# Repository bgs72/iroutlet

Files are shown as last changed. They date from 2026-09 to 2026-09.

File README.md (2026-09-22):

# IrOutlet
IrOutlet is an 8-port power outlet. Each power outlet can be switched on or off using an IR remote.

## Design details
A [TSOP4836](KiCad/doc/tsop4836.pdf) IR receiver converts the IR light into a bit stream. This bit stream is decoded by a [PIC16F15325](KiCad/doc/pic16f15325.pdf) microcontroller.
When the IR signal is decoded, the microcontroller performs an action if the signal matches a supported IR address/command listed below:

| Address | Command | Action |
|---|---| ---|
| `0b00101` | `0b00000000` | Switch all outlets on  |
| `0b00101` | `0b00000001` | Switch outlet 1 on |
| `0b00101` | `0b00000010` | Switch outlet 2 on |
| `0b00101` | `0b00000011` | Switch outlet 3 on |
| `0b00101` | `0b00000100` | Switch outlet 4 on |
| `0b00101` | `0b00000101` | Switch outlet 5 on |
| `0b00101` | `0b00000110` | Switch outlet 6 on |
| `0b00101` | `0b00000111` | Switch outlet 7 on |
| `0b00101` | `0b00001000` | Switch outlet 8 on |
| `0b00101` | `0b00001001` | Switch all outlets off |
| `0b00101` | `0b00100000` | Switch outlet 1 off |
| `0b00101` | `0b00100001` | Switch outlet 2 off |
| `0b00101` | `0b00110010` | Switch outlet 3 off |
| `0b00101` | `0b00110101` | Switch outlet 4 off |
| `0b00101` | `0b00110100` | Switch outlet 5 off |
| `0b00101` | `0b00110110` | Switch outlet 6 off |
| `0b00101` | `0b00101001` | Switch outlet 7 off |
| `0b00101` | `0b00111110` | Switch outlet 8 off |

## Notes

1. Address `0b00101` corresponds to the address of a Marantz remote control I had available.

2. Below are some oscilloscope captures measured at the output pin of the [TSOP4836](KiCad/doc/tsop4836.pdf) while using the Marantz remote control:<br>
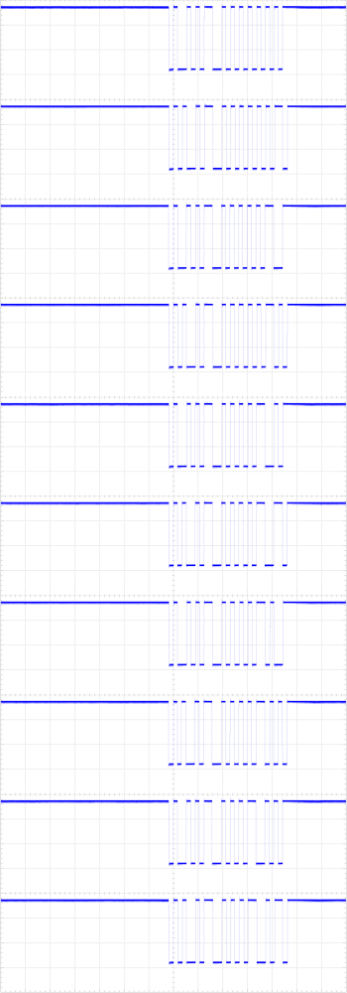
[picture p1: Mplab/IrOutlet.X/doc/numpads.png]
IR captures
  

## Development tree

The project consists of three major folders:

1. [Mplab](https://www.microchip.com/en-us/tools-resources/develop/mplab-x-ide)
  
  This folder contains the bare-metal code for the Microchip [PIC16F15325](KiCad/doc/pic16f15325.pdf) controller.
  [MPLAB X IDE](https://www.microchip.com/en-us/tools-resources/develop/mplab-x-ide) or [VSCode](https://code.visualstudio.com/) with the MPLAB extension can be used as the development environment (using the free [XC8](https://www.microchip.com/en-us/tools-resources/develop/mplab-xc-compilers/xc8) compiler).
  
  Major implementation files:
  - [rc5.h](Mplab/IrOutlet.X/rc5.h): RC5 decoder API
  - [rc5.c](Mplab/IrOutlet.X/rc5.c): RC5 decoder implementation
  - [interrupts.c](Mplab/IrOutlet.X/interrupts.c): [TSOP4836](KiCad/doc/tsop4836.pdf) and timer interrupt handlers
  - [main.c](Mplab/IrOutlet.X/main.c): Controller setup and IR handling

2. [KiCad](https://www.kicad.org)
    
    This folder contains the IrOutlet schematic and PCB design.

    - The schematic consists of two major parts:
      1. The controller:<br>
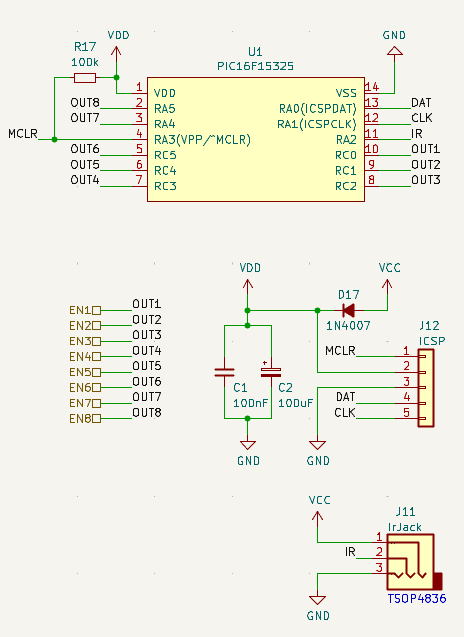
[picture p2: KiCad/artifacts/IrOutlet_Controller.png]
IrOutlet Controller
        
      2. The relay driver:<br>
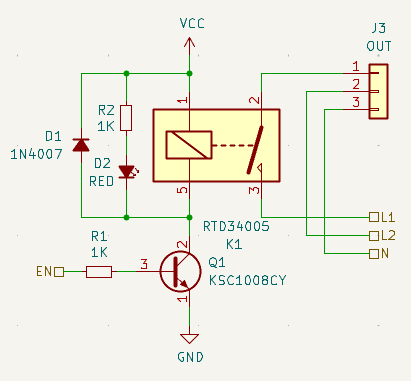
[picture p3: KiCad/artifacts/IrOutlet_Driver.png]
IrOutlet Driver
        
    - The components are laid out on a single-sided PCB:
      1. Component layout:<br>
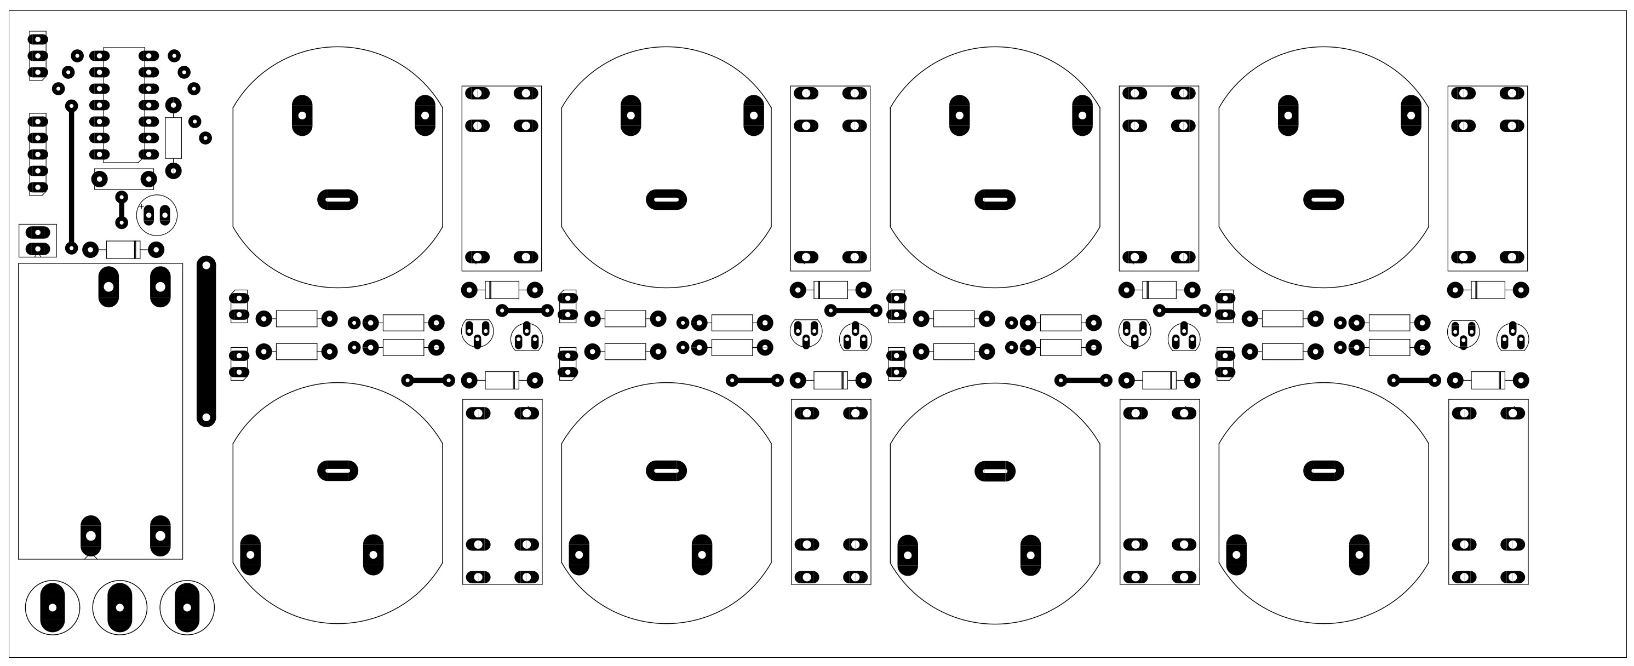
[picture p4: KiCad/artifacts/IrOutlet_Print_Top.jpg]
IrOutlet Component Layout
        
      2. Bottom mask:<br>
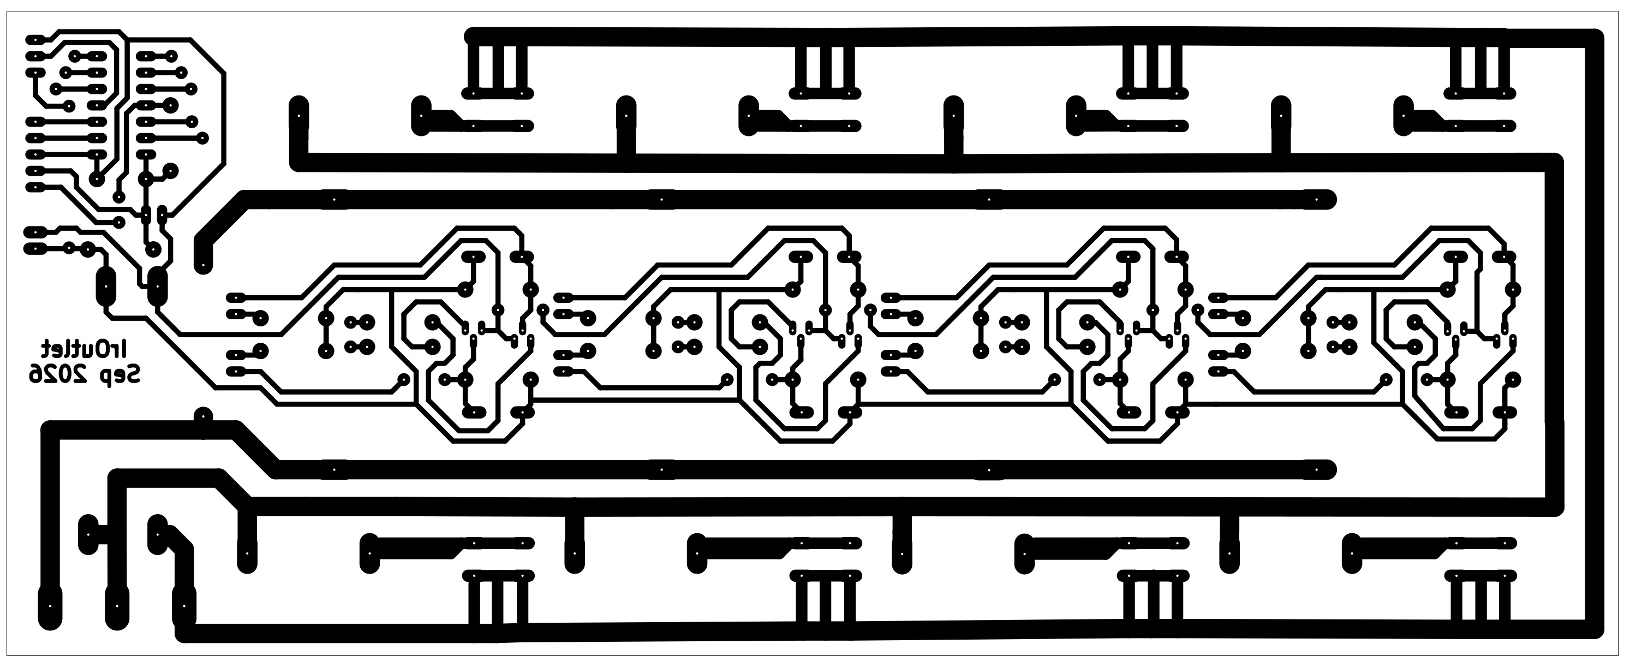
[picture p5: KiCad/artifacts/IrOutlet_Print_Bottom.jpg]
IrOutlet Bottom Mask
        
 
3. [FreeCAD](https://www.freecad.org)

    This folder contains the 3D enclosure model for the IrOutlet.
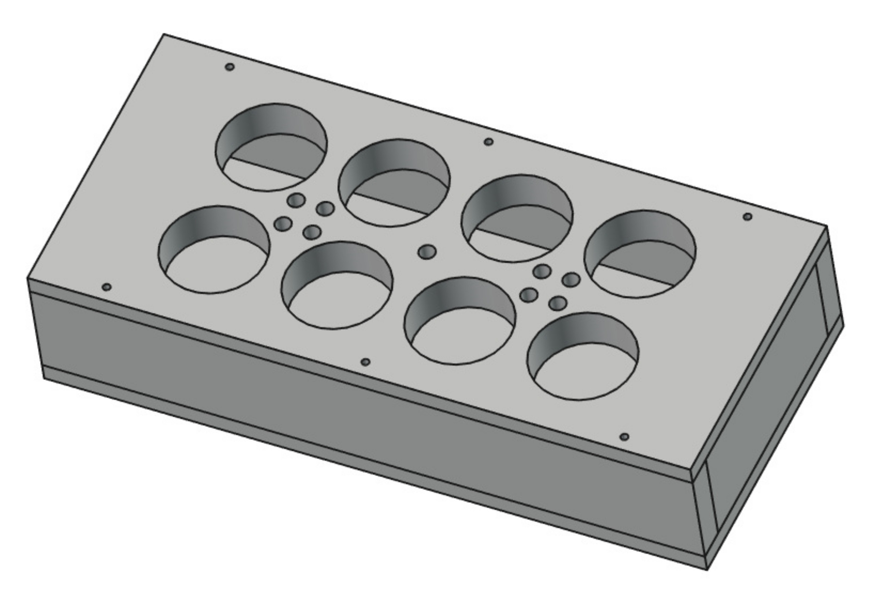
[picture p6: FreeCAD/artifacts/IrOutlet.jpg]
IrOutlet 3D model


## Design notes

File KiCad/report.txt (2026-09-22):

Info: Processing symbol 'K8:IrOutlet:RELAY_TE_RTD3405'.
Info: Processing symbol 'R15:IrOutlet:RES_H'.
Info: Processing symbol 'R6:IrOutlet:RES_H'.
Info: Processing symbol 'K6:IrOutlet:RELAY_TE_RTD3405'.
Info: Processing symbol 'J6:IrOutlet:OUTLET'.
Info: Processing symbol 'R16:IrOutlet:RES_H'.
Info: Processing symbol 'J5:IrOutlet:OUTLET'.
Info: Processing symbol 'R5:IrOutlet:RES_H'.
Info: Processing symbol 'R17:IrOutlet:RES_H'.
Info: Processing symbol 'J4:IrOutlet:OUTLET'.
Info: Processing symbol 'J7:IrOutlet:OUTLET'.
Info: Processing symbol 'R4:IrOutlet:RES_H'.
Info: Processing symbol 'U1:IrOutlet:DIP-14'.
Info: Processing symbol 'J3:IrOutlet:OUTLET'.
Info: Processing symbol 'J2:IrOutlet:TB_1x2'.
Info: Processing symbol 'PS1:IrOutlet:IRM-05-5'.
Info: Processing symbol 'C1:IrOutlet:C_L7.62mm_W3.2mm'.
Info: Processing symbol 'R3:IrOutlet:RES_H'.
Info: Processing symbol 'J1:IrOutlet:TB_1x3'.
Info: Processing symbol 'D17:IrOutlet:DIODE_H'.
Info: Processing symbol 'J10:IrOutlet:OUTLET'.
Info: Processing symbol 'R10:IrOutlet:RES_H'.
Info: Processing symbol 'K1:IrOutlet:RELAY_TE_RTD3405'.
Info: Processing symbol 'K2:IrOutlet:RELAY_TE_RTD3405'.
Info: Processing symbol 'J12:IrOutlet:HDR_1x5'.
Info: Processing symbol 'R11:IrOutlet:RES_H'.
Info: Processing symbol 'J11:IrOutlet:HDR_1x3'.
Info: Processing symbol 'R9:IrOutlet:RES_H'.
Info: Processing symbol 'K3:IrOutlet:RELAY_TE_RTD3405'.
Info: Processing symbol 'R12:IrOutlet:RES_H'.
Info: Processing symbol 'K7:IrOutlet:RELAY_TE_RTD3405'.
Info: Processing symbol 'R8:IrOutlet:RES_H'.
Info: Processing symbol 'R13:IrOutlet:RES_H'.
Info: Processing symbol 'J9:IrOutlet:OUTLET'.
Info: Processing symbol 'K4:IrOutlet:RELAY_TE_RTD3405'.
Info: Processing symbol 'J8:IrOutlet:OUTLET'.
Info: Processing symbol 'R7:IrOutlet:RES_H'.
Info: Processing symbol 'R14:IrOutlet:RES_H'.
Info: Processing symbol 'K5:IrOutlet:RELAY_TE_RTD3405'.
Info: Processing symbol 'Q8:IrOutlet:TO-92'.
Info: Processing symbol 'D12:IrOutlet:HDR_1x2'.
Info: Processing symbol 'C2:IrOutlet:CAP_6.3mm_P2.50mm'.
Info: Processing symbol 'R1:IrOutlet:RES_H'.
Info: Processing symbol 'D11:IrOutlet:DIODE_H'.
Info: Processing symbol 'Q4:IrOutlet:TO-92'.
Info: Processing symbol 'D10:IrOutlet:HDR_1x2'.
Info: Processing symbol 'R2:IrOutlet:RES_H'.
Info: Processing symbol 'D2:IrOutlet:HDR_1x2'.
Info: Processing symbol 'D9:IrOutlet:DIODE_H'.
Info: Processing symbol 'D1:IrOutlet:DIODE_H'.
Info: Processing symbol 'Q5:IrOutlet:TO-92'.
Info: Processing symbol 'D3:IrOutlet:DIODE_H'.
Info: Processing symbol 'D8:IrOutlet:HDR_1x2'.
Info: Processing symbol 'D4:IrOutlet:HDR_1x2'.
Info: Processing symbol 'D7:IrOutlet:DIODE_H'.
Info: Processing symbol 'Q6:IrOutlet:TO-92'.
Info: Processing symbol 'D6:IrOutlet:HDR_1x2'.
Info: Processing symbol 'Q7:IrOutlet:TO-92'.
Info: Processing symbol 'D5:IrOutlet:DIODE_H'.
Info: Processing symbol 'D16:IrOutlet:HDR_1x2'.
Info: Processing symbol 'Q1:IrOutlet:TO-92'.
Info: Processing symbol 'D13:IrOutlet:DIODE_H'.
Info: Processing symbol 'Q3:IrOutlet:TO-92'.
Info: Processing symbol 'D14:IrOutlet:HDR_1x2'.
Info: Processing symbol 'D15:IrOutlet:DIODE_H'.
Info: Processing symbol 'Q2:IrOutlet:TO-92'.
Reconnect R8 pin 2 from /RelaisDriver1.4/EN to /IrController/OUT4.
Reconnect R10 pin 1 from Net-(Q5-Pad3) to Net-(Q5-B).
Add net /IrController/OUT4.
Add net /IrController/OUT5.
Reconnect R2 pin 1 from Net-(Q1-Pad3) to Net-(Q1-B).
Change R3 reference designator to R2.
Reconnect R10 pin 2 from /RelaisDriver2.1/EN to /IrController/OUT5.
Reconnect R8 pin 1 from Net-(Q4-Pad3) to Net-(Q4-B).
Add net Net-(Q4-B).
Update R8 footprint filters to 'R_*'.
Update R8 sheetfile to 'RelaisDriver1.kicad_sch'.
Update R8 sheetname to '/RelaisDriver1.4/'.
Update R8 fields.
Change R8 reference designator to R7.
Update R10 unit metadata.
Update R9 footprint filters to 'R_*'.
Update R10 fields.
Change R10 reference designator to R9.
Update R10 sheetname to '/RelaisDriver2.1/'.
Update R9 unit metadata.
Update R10 sheetfile to 'RelaisDriver2.kicad_sch'.
Update R2 unit metadata.
Reconnect R9 pin 1 from Net-(D9-Pad2) to Net-(D8-A).
Add net Net-(D8-A).
Add net Net-(Q1-B).
Update R8 unit metadata.
Reconnect R2 pin 2 from /RelaisDriver1.1/EN to /IrController/OUT1.
Update R10 footprint filters to 'R_*'.
Update R9 sheetfile to 'RelaisDriver1.kicad_sch'.
Add net /IrController/OUT1.
Update R9 sheetname to '/RelaisDriver1.4/'.
Add net Net-(Q5-B).
Update R9 fields.
Change R9 reference designator to R8.
Add net /IrController/OUT2.
Reconnect R5 pin 1 from Net-(D5-Pad2) to Net-(D4-A).
Add net Net-(D4-A).
Update R5 footprint filters to 'R_*'.
Update R5 sheetfile to 'RelaisDriver1.kicad_sch'.
Update R5 sheetname to '/RelaisDriver1.2/'.
Update R5 fields.
Change R5 reference designator to R4.
Update R3 footprint filters to 'R_*'.
Update R4 unit metadata.
Reconnect R4 pin 2 from /RelaisDriver1.2/EN to /IrController/OUT2.
Update R5 unit metadata.
Reconnect R4 pin 1 from Net-(Q2-Pad3) to Net-(Q2-B).
Add net Net-(Q2-B).
Update R4 footprint filters to 'R_*'.
Update R4 sheetfile to 'RelaisDriver1.kicad_sch'.
Add net Net-(D2-A).
Update R4 sheetname to '/RelaisDriver1.2/'.
Update R4 fields.
Change R4 reference designator to R3.
Reconnect R3 pin 1 from Net-(D3-Pad2) to Net-(D2-A).
Update R3 unit metadata.
Reconnect R6 pin 1 from Net-(Q3-Pad3) to Net-(Q3-B).
Update R3 fields.
Reconnect R7 pin 1 from Net-(D7-Pad2) to Net-(D6-A).
Add net Net-(D6-A).
Update R7 footprint filters to 'R_*'.
Update R7 sheetfile to 'RelaisDriver1.kicad_sch'.
Update R7 sheetname to '/RelaisDriver1.3/'.
Update R7 fields.
Change R7 reference designator to R6.
Update R3 sheetname to '/RelaisDriver1.1/'.
Update R6 unit metadata.
Update R7 unit metadata.
Add net Net-(Q3-B).
Reconnect R6 pin 2 from /RelaisDriver1.3/EN to /IrController/OUT3.
Add net /IrController/OUT3.
Update R6 footprint filters to 'R_*'.
Update R6 sheetfile to 'RelaisDriver1.kicad_sch'.
Update R6 sheetname to '/RelaisDriver1.3/'.
Update R6 fields.
Update R3 sheetfile to 'RelaisDriver1.kicad_sch'.
Change R6 reference designator to R5.
Add net /IrController/OUT6.
Update R1 sheetfile to 'IrController.kicad_sch'.
Reconnect U1 pin 9 from /RelaisDriver1.2/EN to /IrController/OUT2.
Reconnect U1 pin 8 from /RelaisDriver1.3/EN to /IrController/OUT3.
Reconnect U1 pin 10 from /RelaisDriver1.1/EN to /IrController/OUT1.
Reconnect U1 pin 6 from /RelaisDriver2.1/EN to /IrController/OUT5.
Reconnect U1 pin 5 from /RelaisDriver2.2/EN to /IrController/OUT6.
Reconnect U1 pin 7 from /RelaisDriver1.4/EN to /IrController/OUT4.
Reconnect U1 pin 3 from /RelaisDriver2.4/EN to /IrController/OUT7.
Update U1 sheetfile to 'IrController.kicad_sch'.
Update U1 sheetname to '/IrController/'.
Update U1 fields.
Update R1 unit metadata.
Update R1 footprint filters to 'R_*'.
Reconnect U1 pin 2 from /RelaisDriver2.3/EN to /IrController/OUT8.
Update R1 sheetname to '/IrController/'.
Update R1 fields.
Change R1 reference designator to R17.
Update R17 unit metadata.
Reconnect R17 pin 1 from Net-(D17-Pad2) to Net-(D16-A).
Add net Net-(D16-A).
Update R17 footprint filters to 'R_*'.
Update R17 sheetfile to 'RelaisDriver2.kicad_sch'.
Update R17 sheetname to '/RelaisDriver2.3/'.
Update R17 fields.
Change R17 reference designator to R16.
Update R16 unit metadata.
Reconnect via from /RelaisDriver1.3/EN to /IrController/OUT3.
Reconnect via from /RelaisDriver1.1/EN to /IrController/OUT1.
Reconnect via from /RelaisDriver1.1/EN to /IrController/OUT1.
Reconnect via from /RelaisDriver2.3/EN to /IrController/OUT8.
Reconnect via from /RelaisDriver2.3/EN to /IrController/OUT8.
Reconnect via from /RelaisDriver2.4/EN to /IrController/OUT7.
Reconnect via from /RelaisDriver2.4/EN to /IrController/OUT7.
Reconnect via from /RelaisDriver2.2/EN to /IrController/OUT6.
Reconnect via from /RelaisDriver2.2/EN to /IrController/OUT6.
Reconnect via from /RelaisDriver2.1/EN to /IrController/OUT5.
Reconnect via from /RelaisDriver2.1/EN to /IrController/OUT5.
Reconnect via from /RelaisDriver1.4/EN to /IrController/OUT4.
Reconnect via from /RelaisDriver1.4/EN to /IrController/OUT4.
Reconnect R16 pin 1 from Net-(Q8-Pad3) to Net-(Q8-B).
Reconnect via from /RelaisDriver1.3/EN to /IrController/OUT3.
Reconnect via from /RelaisDriver1.2/EN to /IrController/OUT2.
Reconnect via from /RelaisDriver1.2/EN to /IrController/OUT2.
Reconnect via from Net-(D16-Pad2) to Net-(D15-A).
Reconnect via from Net-(D16-Pad2) to Net-(D15-A).
Reconnect via from Net-(D14-Pad2) to Net-(D13-A).
Reconnect via from Net-(D14-Pad2) to Net-(D13-A).
Reconnect via from Net-(D12-Pad2) to Net-(D11-A).
Reconnect via from Net-(D12-Pad2) to Net-(D11-A).
Reconnect via from Net-(D10-Pad2) to Net-(D10-K).
Reconnect via from Net-(D10-Pad2) to Net-(D10-K).
Update U1 unit metadata.
Add net Net-(Q6-B).
Update R13 unit metadata.
Reconnect R13 pin 1 from Net-(D13-Pad2) to Net-(D12-A).
Add net Net-(D12-A).
Update R13 footprint filters to 'R_*'.
Update R13 sheetfile to 'RelaisDriver2.kicad_sch'.
Update R13 sheetname to '/RelaisDriver2.2/'.
Update R13 fields.
Change R13 reference designator to R12.
Update R12 unit metadata.
Reconnect R12 pin 2 from /RelaisDriver2.2/EN to /IrController/OUT6.
Update PS1 sheetfile to 'PowerSupply.kicad_sch'.
Reconnect R12 pin 1 from Net-(Q6-Pad3) to Net-(Q6-B).
Change R14 reference designator to R13.
Update R12 footprint filters to 'R_*'.
Update R12 sheetfile to 'RelaisDriver2.kicad_sch'.
Update R12 sheetname to '/RelaisDriver2.2/'.
Update R12 fields.
Change R12 reference designator to R11.
Update R11 unit metadata.
Reconnect R11 pin 1 from Net-(D11-Pad2) to Net-(D10-A).
Add net Net-(D10-A).
Update R11 footprint filters to 'R_*'.
Update R11 sheetfile to 'RelaisDriver2.kicad_sch'.
Update R11 sheetname to '/RelaisDriver2.1/'.
Update R11 fields.
Update R15 sheetfile to 'RelaisDriver2.kicad_sch'.
Add net Net-(Q8-B).
Reconnect R16 pin 2 from /RelaisDriver2.3/EN to /IrController/OUT8.
Add net /IrController/OUT8.
Update R16 footprint filters to 'R_*'.
Update R16 sheetfile to 'RelaisDriver2.kicad_sch'.
Update R16 sheetname to '/RelaisDriver2.3/'.
Update R16 fields.
Change R16 reference designator to R15.
Update R15 unit metadata.
Reconnect R15 pin 1 from Net-(D15-Pad2) to Net-(D14-A).
Add net Net-(D14-A).
Update R15 footprint filters to 'R_*'.
Change R11 reference designator to R10.
Update R15 sheetname to '/RelaisDriver2.4/'.
Update R15 fields.
Change R15 reference designator to R14.
Update R14 unit metadata.
Reconnect R14 pin 2 from /RelaisDriver2.4/EN to /IrController/OUT7.
Add net /IrController/OUT7.
Reconnect R14 pin 1 from Net-(Q7-Pad3) to Net-(Q7-B).
Add net Net-(Q7-B).
Update R14 footprint filters to 'R_*'.
Update R14 sheetfile to 'RelaisDriver2.kicad_sch'.
Update R14 sheetname to '/RelaisDriver2.4/'.
Update R14 fields.
Update J4 fields.
Add net Net-(J7-Pin_2).
Update J5 footprint filters to 'Connector*:*_1x??_*'.
Update J5 sheetfile to 'RelaisDriver2.kicad_sch'.
Update J5 sheetname to '/RelaisDriver2.1/'.
Update J5 fields.
Change J5 reference designator to J7.
Update J4 unit metadata.
Reconnect J4 pin 1 from Net-(J4-Pad1) to Net-(J6-Pin_1).
Add net Net-(J6-Pin_1).
Update J4 footprint filters to 'Connector*:*_1x??_*'.
Update J4 sheetfile to 'RelaisDriver1.kicad_sch'.
Update J4 sheetname to '/RelaisDriver1.4/'.
Reconnect J5 pin 2 from Net-(J5-Pad2) to Net-(J7-Pin_2).
Change J4 reference designator to J6.
Update J3 unit metadata.
Reconnect J3 pin 1 from Net-(J3-Pad1) to Net-(J5-Pin_1).
Add net Net-(J5-Pin_1).
Update J3 footprint filters to 'Connector*:*_1x??_*'.
Update J3 sheetfile to 'RelaisDriver1.kicad_sch'.
Update J3 sheetname to '/RelaisDriver1.3/'.
Update J3 fields.
Change J3 reference designator to J5.
Update J2 unit metadata.
Reconnect J2 pin 1 from Net-(J2-Pad1) to Net-(J4-Pin_1).
Update J7 sheetname to '/RelaisDriver2.4/'.
Reconnect J8 pin 2 from Net-(J8-Pad2) to Net-(J10-Pin_2).
Add net Net-(J10-Pin_2).
Update J8 footprint filters to 'Connector*:*_1x??_*'.
Update J8 sheetfile to 'RelaisDriver2.kicad_sch'.
Update J8 sheetname to '/RelaisDriver2.3/'.
Update J8 fields.
Change J8 reference designator to J10.
Update J7 unit metadata.
Reconnect J7 pin 2 from Net-(J7-Pad2) to Net-(J9-Pin_2).
Add net Net-(J9-Pin_2).
Update J7 footprint filters to 'Connector*:*_1x??_*'.
Update J7 sheetfile to 'RelaisDriver2.kicad_sch'.
Add net Net-(J4-Pin_1).
Update J7 fields.
Change J7 reference designator to J9.
Update J6 unit metadata.
Reconnect J6 pin 2 from Net-(J6-Pad2) to Net-(J8-Pin_2).
Add net Net-(J8-Pin_2).
Update J6 footprint filters to 'Connector*:*_1x??_*'.
Update J6 sheetfile to 'RelaisDriver2.kicad_sch'.
Update J6 sheetname to '/RelaisDriver2.2/'.
Update J6 fields.
Change J6 reference designator to J8.
Update J5 unit metadata.
Add D6 (footprint 'IrOutlet:HDR_1x2').
Change J9 reference designator to J1.
Add D17 (footprint 'IrOutlet:DIODE_H').
Add D16 (footprint 'IrOutlet:HDR_1x2').
Add D15 (footprint 'IrOutlet:DIODE_H').
Add D14 (footprint 'IrOutlet:HDR_1x2').
Add D13 (footprint 'IrOutlet:DIODE_H').
Add D12 (footprint 'IrOutlet:HDR_1x2').
Add D11 (footprint 'IrOutlet:DIODE_H').
Add D10 (footprint 'IrOutlet:HDR_1x2').
Add D9 (footprint 'IrOutlet:DIODE_H').
Add D8 (footprint 'IrOutlet:HDR_1x2').
Add D7 (footprint 'IrOutlet:DIODE_H').
Update J9 fields.
Add D5 (footprint 'IrOutlet:DIODE_H').
Add D4 (footprint 'IrOutlet:HDR_1x2').
Add D3 (footprint 'IrOutlet:DIODE_H').
Add D2 (footprint 'IrOutlet:HDR_1x2').
Add D1 (footprint 'IrOutlet:DIODE_H').
Add C2 (footprint 'IrOutlet:CAP_6.3mm_P2.50mm').
Update C1 unit metadata.
Update C1 footprint filters to 'C_*'.
Update C1 sheetfile to 'IrController.kicad_sch'.
Update C1 sheetname to '/IrController/'.
Update C1 fields.
Update J1 fields.
Update J2 footprint filters to 'Connector*:*_1x??_*'.
Update J2 sheetfile to 'RelaisDriver1.kicad_sch'.
Update J2 sheetname to '/RelaisDriver1.2/'.
Update J2 fields.
Change J2 reference designator to J4.
Update J1 unit metadata.
Reconnect J1 pin 1 from Net-(J1-Pad1) to Net-(J3-Pin_1).
Add net Net-(J3-Pin_1).
Update J1 footprint filters to 'Connector*:*_1x??_*'.
Update J1 sheetfile to 'RelaisDriver1.kicad_sch'.
Update J1 sheetname to '/RelaisDriver1.1/'.
Update J8 unit metadata.
Change J1 reference designator to J3.
Update J10 unit metadata.
Update J10 footprint filters to 'TerminalBlock*:*'.
Update J10 sheetfile to 'PowerSupply.kicad_sch'.
Update J10 sheetname to '/PowerSupply/'.
Update J10 fields.
Change J10 reference designator to J2.
Update J9 unit metadata.
Update J9 footprint filters to 'TerminalBlock*:*'.
Update J9 sheetfile to 'PowerSupply.kicad_sch'.
Update J9 sheetname to '/PowerSupply/'.
Add net Net-(D11-A).
Update K7 unit metadata.
Reconnect K7 pin 2 from Net-(J7-Pad2) to Net-(J9-Pin_2).
Reconnect K7 pin 2 from Net-(J7-Pad2) to Net-(J9-Pin_2).
Reconnect K7 pin 5 from Net-(D14-Pad2) to Net-(D13-A).
Add net Net-(D13-A).
Update K7 footprint filters to 'Relay*SPST*TE*PCH*1***2M*'.
Update K7 sheetfile to 'RelaisDriver2.kicad_sch'.
Update K7 sheetname to '/RelaisDriver2.4/'.
Update K7 fields.
Update K6 unit metadata.
Reconnect K6 pin 2 from Net-(J6-Pad2) to Net-(J8-Pin_2).
Reconnect K6 pin 5 from Net-(D12-Pad2) to Net-(D11-A).
Update K8 fields.
Reconnect K6 pin 2 from Net-(J6-Pad2) to Net-(J8-Pin_2).
Update K6 footprint filters to 'Relay*SPST*TE*PCH*1***2M*'.
Update K6 sheetfile to 'RelaisDriver2.kicad_sch'.
Update K6 sheetname to '/RelaisDriver2.2/'.
Update K6 fields.
Update K5 unit metadata.
Reconnect K5 pin 2 from Net-(J5-Pad2) to Net-(J7-Pin_2).
Reconnect K5 pin 2 from Net-(J5-Pad2) to Net-(J7-Pin_2).
Reconnect K5 pin 5 from Net-(D10-Pad2) to Net-(D10-K).
Add net Net-(D10-K).
Update K5 footprint filters to 'Relay*SPST*TE*PCH*1***2M*'.
Update PS1 unit metadata.
Update R2 sheetfile to 'RelaisDriver1.kicad_sch'.
Update R2 sheetname to '/RelaisDriver1.1/'.
Update R2 fields.
Change R2 reference designator to R1.
Add Q8 (footprint 'IrOutlet:TO-92').
Add Q7 (footprint 'IrOutlet:TO-92').
Add Q6 (footprint 'IrOutlet:TO-92').
Add Q5 (footprint 'IrOutlet:TO-92').
Add Q4 (footprint 'IrOutlet:TO-92').
Add Q3 (footprint 'IrOutlet:TO-92').
Add Q2 (footprint 'IrOutlet:TO-92').
Add Q1 (footprint 'IrOutlet:TO-92').
Update K5 sheetfile to 'RelaisDriver2.kicad_sch'.
Update PS1 footprint filters to 'Converter*ACDC*MeanWell*IRM*05*THT*'.
Update PS1 sheetname to '/PowerSupply/'.
Update PS1 fields.
Update K8 unit metadata.
Reconnect K8 pin 2 from Net-(J8-Pad2) to Net-(J10-Pin_2).
Reconnect K8 pin 5 from Net-(D16-Pad2) to Net-(D15-A).
Add net Net-(D15-A).
Reconnect K8 pin 2 from Net-(J8-Pad2) to Net-(J10-Pin_2).
Update K8 footprint filters to 'Relay*SPST*TE*PCH*1***2M*'.
Update K8 sheetfile to 'RelaisDriver2.kicad_sch'.
Update K8 sheetname to '/RelaisDriver2.3/'.
Update K1 sheetname to '/RelaisDriver1.1/'.
Reconnect K2 pin 2 from Net-(J2-Pad1) to Net-(J4-Pin_1).
Update K2 footprint filters to 'Relay*SPST*TE*PCH*1***2M*'.
Update K2 sheetfile to 'RelaisDriver1.kicad_sch'.
Update K2 sheetname to '/RelaisDriver1.2/'.
Update K2 fields.
Update K1 unit metadata.
Reconnect K1 pin 2 from Net-(J1-Pad1) to Net-(J3-Pin_1).
Reconnect K1 pin 5 from Net-(D2-Pad2) to Net-(D1-A).
Add net Net-(D1-A).
Reconnect K1 pin 2 from Net-(J1-Pad1) to Net-(J3-Pin_1).
Update K1 footprint filters to 'Relay*SPST*TE*PCH*1***2M*'.
Update K1 sheetfile to 'RelaisDriver1.kicad_sch'.
Add net Net-(D3-A).
Update K1 fields.
Update J12 unit metadata.
Update J12 footprint filters to 'Connector*:*_1x??_*'.
Update J12 sheetfile to 'IrController.kicad_sch'.
Update J12 sheetname to '/IrController/'.
Update J12 fields.
Update J11 unit metadata.
Update J11 footprint filters to 'Jack*'.
Update J11 sheetfile to 'IrController.kicad_sch'.
Update J11 sheetname to '/IrController/'.
Update J11 fields.
Update K3 unit metadata.
Update K5 sheetname to '/RelaisDriver2.1/'.
Update K5 fields.
Update K4 unit metadata.
Reconnect K4 pin 2 from Net-(J4-Pad1) to Net-(J6-Pin_1).
Reconnect K4 pin 5 from Net-(D8-Pad2) to Net-(D7-A).
Add net Net-(D7-A).
Reconnect K4 pin 2 from Net-(J4-Pad1) to Net-(J6-Pin_1).
Update K4 footprint filters to 'Relay*SPST*TE*PCH*1***2M*'.
Update K4 sheetfile to 'RelaisDriver1.kicad_sch'.
Update K4 sheetname to '/RelaisDriver1.4/'.
Update K4 fields.
Update R2 footprint filters to 'R_*'.
Reconnect K3 pin 2 from Net-(J3-Pad1) to Net-(J5-Pin_1).
Reconnect K3 pin 5 from Net-(D6-Pad2) to Net-(D5-A).
Add net Net-(D5-A).
Reconnect K3 pin 2 from Net-(J3-Pad1) to Net-(J5-Pin_1).
Update K3 footprint filters to 'Relay*SPST*TE*PCH*1***2M*'.
Update K3 sheetfile to 'RelaisDriver1.kicad_sch'.
Update K3 sheetname to '/RelaisDriver1.3/'.
Update K3 fields.
Update K2 unit metadata.
Reconnect K2 pin 2 from Net-(J2-Pad1) to Net-(J4-Pin_1).
Reconnect K2 pin 5 from Net-(D4-Pad2) to Net-(D3-A).

Info: Total warnings: 0, errors: 0.

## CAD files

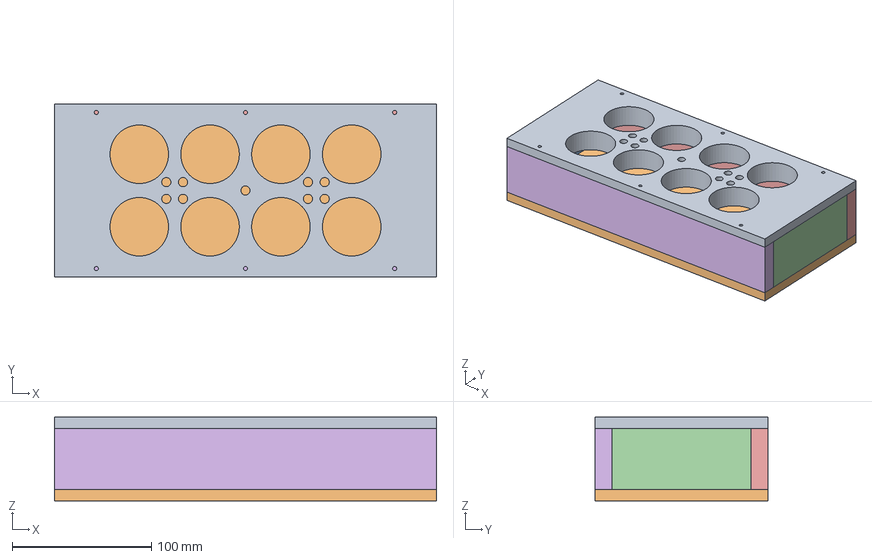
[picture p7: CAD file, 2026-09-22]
FreeCAD/IrOutlet.FCStd
274.0 x 124.0 x 60.0 mm
top.body
bottom.body
left.body
right.body
front.body
rear.body

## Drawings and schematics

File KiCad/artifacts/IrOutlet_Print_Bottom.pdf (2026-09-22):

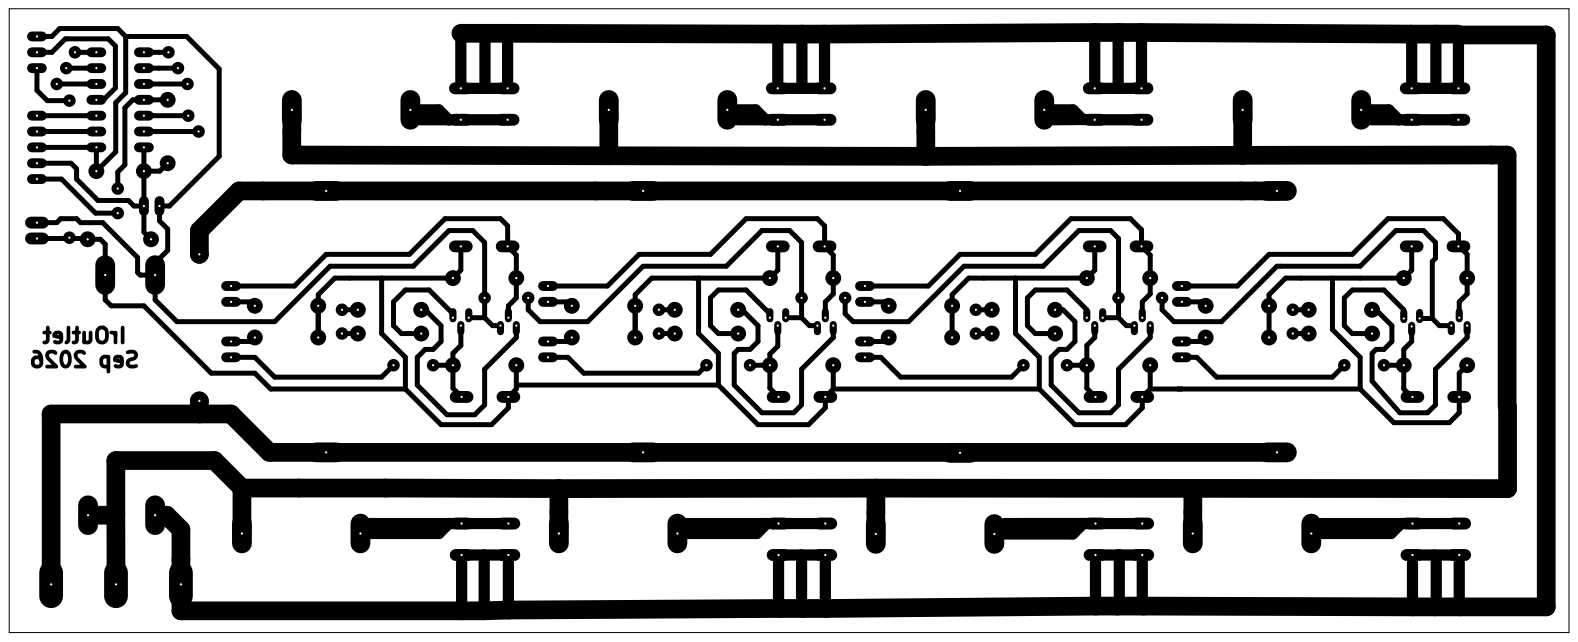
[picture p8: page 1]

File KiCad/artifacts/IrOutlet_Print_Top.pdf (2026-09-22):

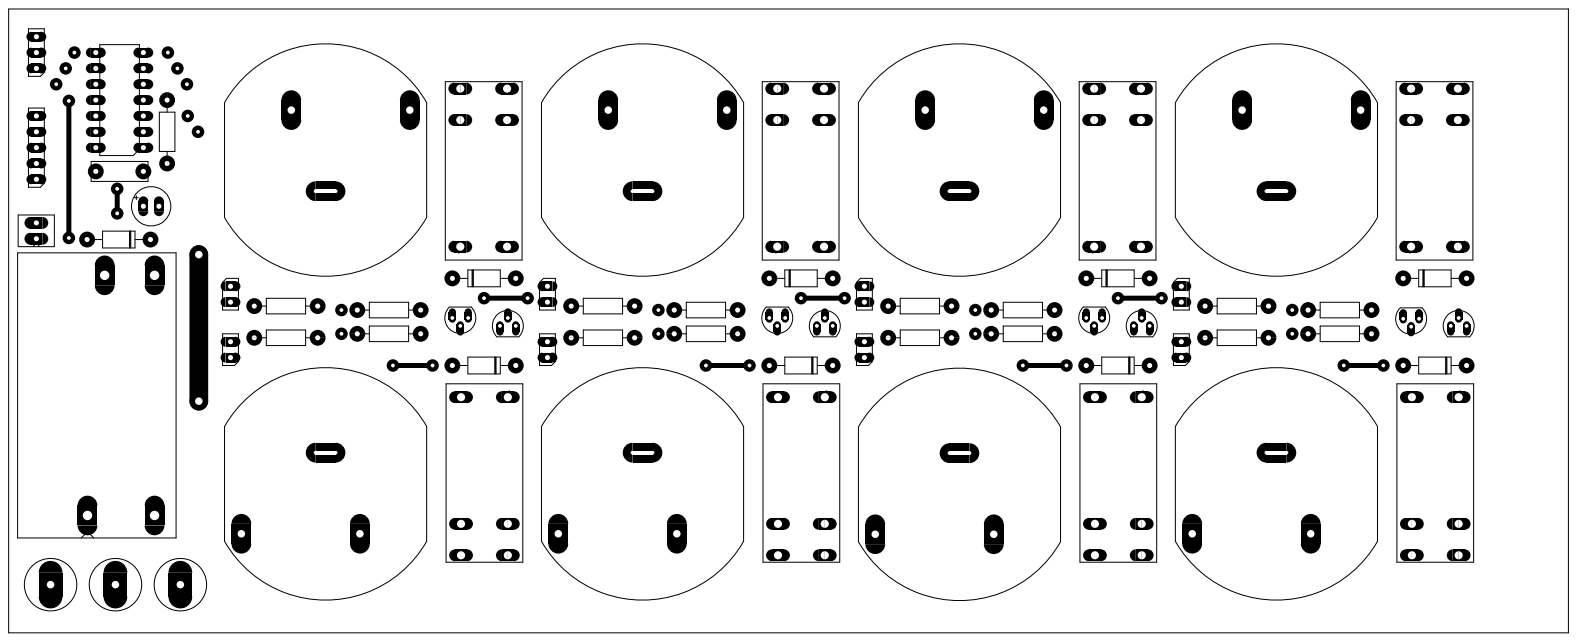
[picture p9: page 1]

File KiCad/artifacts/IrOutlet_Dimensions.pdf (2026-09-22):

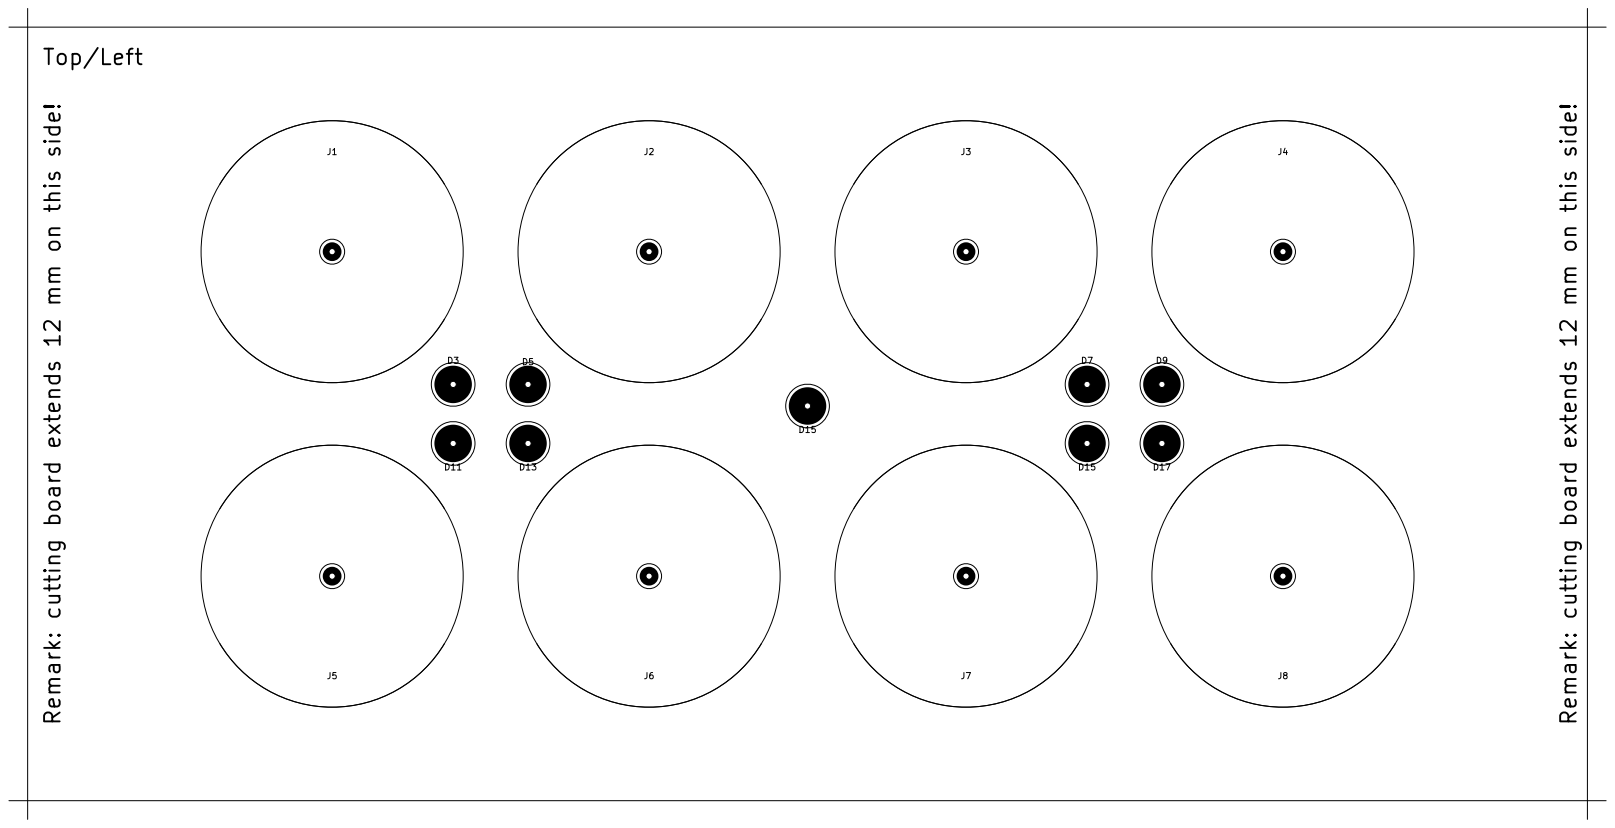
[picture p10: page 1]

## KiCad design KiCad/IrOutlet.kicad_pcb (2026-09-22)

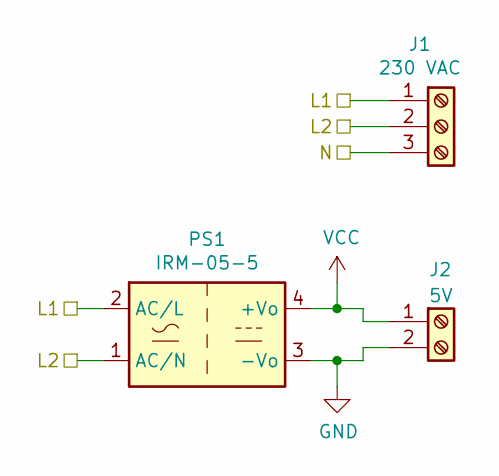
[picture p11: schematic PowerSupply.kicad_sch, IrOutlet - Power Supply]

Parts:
J1: 230 VAC; TB_1x3
J2: 5V; TB_1x2
PS1: IRM-05-5

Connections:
/PowerSupply/L1: J1.1, PS1.2 (AC/L); also elsewhere on the board
/PowerSupply/L2: J1.2, PS1.1 (AC/N); also elsewhere on the board
/PowerSupply/N: J1.3; also elsewhere on the board
GND: J2.2, PS1.3 (-Vo); also elsewhere on the board
VCC: J2.1, PS1.4 (+Vo); also elsewhere on the board

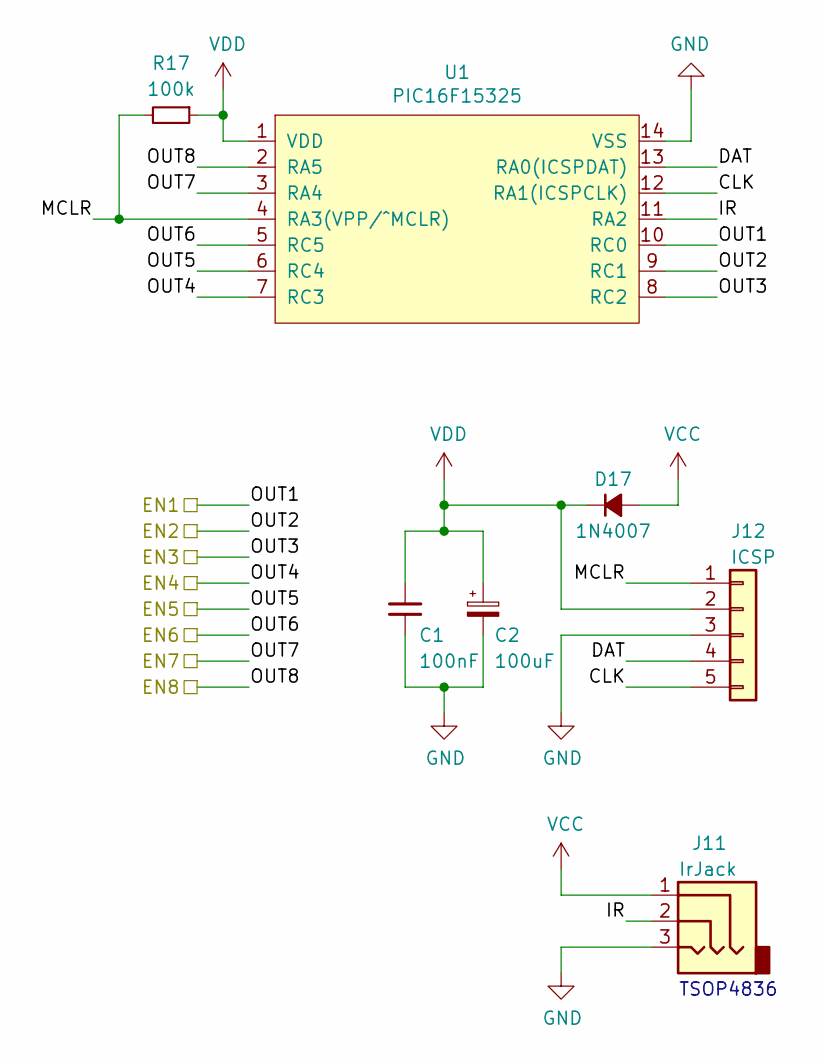
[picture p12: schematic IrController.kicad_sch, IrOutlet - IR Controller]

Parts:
C1: 100nF; C_L7.62mm_W3.2mm
C2: 100uF; CAP_6.3mm_P2.50mm
D17: 1N4007; DIODE_H
J11: IrJack; HDR_1x3
J12: ICSP; HDR_1x5
R17: 100k; RES_H
U1: PIC16F15325; DIP-14

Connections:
/IrController/CLK: J12.5, U1.12 (RA1(ICSPCLK))
/IrController/DAT: J12.4, U1.13 (RA0(ICSPDAT))
/IrController/IR: J11.2, U1.11 (RA2)
/IrController/MCLR: J12.1, R17.2, U1.4 (RA3(VPP/^MCLR))
/IrController/OUT1: U1.10 (RC0); also elsewhere on the board
/IrController/OUT2: U1.9 (RC1); also elsewhere on the board
/IrController/OUT3: U1.8 (RC2); also elsewhere on the board
/IrController/OUT4: U1.7 (RC3); also elsewhere on the board
/IrController/OUT5: U1.6 (RC4); also elsewhere on the board
/IrController/OUT6: U1.5 (RC5); also elsewhere on the board
/IrController/OUT7: U1.3 (RA4); also elsewhere on the board
/IrController/OUT8: U1.2 (RA5); also elsewhere on the board
GND: C1.2, C2.2, J11.3, J12.3, U1.14 (VSS); also elsewhere on the board
VCC: D17.2 (A), J11.1; also elsewhere on the board
VDD: C1.1, C2.1, D17.1 (K), J12.2, R17.1, U1.1 (VDD)

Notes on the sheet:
TSOP4836

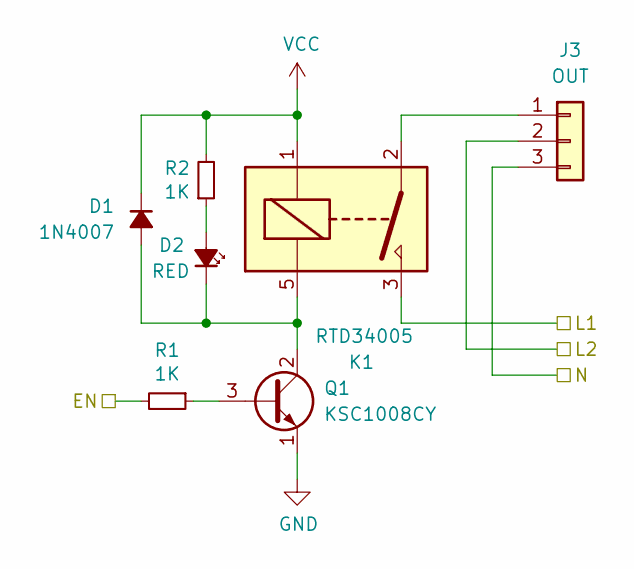
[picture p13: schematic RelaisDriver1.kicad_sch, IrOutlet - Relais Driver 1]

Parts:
D1: 1N4007; DIODE_H
D2: RED; HDR_1x2
J3: OUT; OUTLET
K1: RTD34005; RELAY_TE_RTD3405
Q1: KSC1008CY; TO-92
R1, R2: 1K; RES_H

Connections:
/IrController/OUT1: R1.2; also elsewhere on the board
/PowerSupply/L1: K1.3; also elsewhere on the board
/PowerSupply/L2: J3.2; also elsewhere on the board
/PowerSupply/N: J3.3; also elsewhere on the board
GND: Q1.1 (E); also elsewhere on the board
unnamed: D1.2 (A), D2.1 (K), K1.5, Q1.2 (C)
unnamed: D2.2 (A), R2.1
unnamed: J3.1, K1.2
unnamed: Q1.3 (B), R1.1
VCC: D1.1 (K), K1.1, R2.2; also elsewhere on the board

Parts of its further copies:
D3, D5, D7: 1N4007; DIODE_H
D4, D6, D8: RED; HDR_1x2
J4, J5, J6: OUT; OUTLET
K2, K3, K4: RTD34005; RELAY_TE_RTD3405
Q2, Q3, Q4: KSC1008CY; TO-92
R3, R4, R5, R6, R7, R8: 1K; RES_H

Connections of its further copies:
/IrController/OUT2: R3.2; also elsewhere on the board
/IrController/OUT3: R5.2; also elsewhere on the board
/IrController/OUT4: R7.2; also elsewhere on the board
/PowerSupply/L1: K2.3, K3.3, K4.3; also elsewhere on the board
/PowerSupply/L2: J4.2, J5.2, J6.2; also elsewhere on the board
/PowerSupply/N: J4.3, J5.3, J6.3; also elsewhere on the board
GND: Q2.1 (E), Q3.1 (E), Q4.1 (E); also elsewhere on the board
unnamed: D3.2 (A), D4.1 (K), K2.5, Q2.2 (C)
unnamed: D4.2 (A), R4.1
unnamed: D5.2 (A), D6.1 (K), K3.5, Q3.2 (C)
unnamed: D6.2 (A), R6.1
unnamed: D7.2 (A), D8.1 (K), K4.5, Q4.2 (C)
unnamed: D8.2 (A), R8.1
unnamed: J4.1, K2.2
unnamed: J5.1, K3.2
unnamed: J6.1, K4.2
unnamed: Q2.3 (B), R3.1
unnamed: Q3.3 (B), R5.1
unnamed: Q4.3 (B), R7.1
VCC: D3.1 (K), D5.1 (K), D7.1 (K), K2.1, K3.1, K4.1, R4.2, R6.2, R8.2; also elsewhere on the board

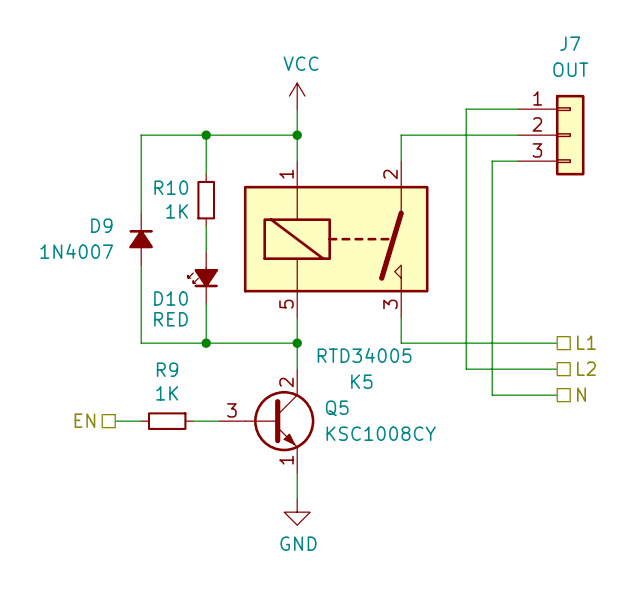
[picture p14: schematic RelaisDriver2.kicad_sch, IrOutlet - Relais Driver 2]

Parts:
D9: 1N4007; DIODE_H
D10: RED; HDR_1x2
J7: OUT; OUTLET
K5: RTD34005; RELAY_TE_RTD3405
Q5: KSC1008CY; TO-92
R9, R10: 1K; RES_H

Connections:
/IrController/OUT5: R9.2; also elsewhere on the board
/PowerSupply/L1: K5.3; also elsewhere on the board
/PowerSupply/L2: J7.1; also elsewhere on the board
/PowerSupply/N: J7.3; also elsewhere on the board
GND: Q5.1 (E); also elsewhere on the board
unnamed: D10.2 (A), R10.1
unnamed: D9.2 (A), D10.1 (K), K5.5, Q5.2 (C)
unnamed: J7.2, K5.2
unnamed: Q5.3 (B), R9.1
VCC: D9.1 (K), K5.1, R10.2; also elsewhere on the board

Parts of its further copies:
D11, D13, D15: 1N4007; DIODE_H
D12, D14, D16: RED; HDR_1x2
J8, J9, J10: OUT; OUTLET
K6, K7, K8: RTD34005; RELAY_TE_RTD3405
Q6, Q7, Q8: KSC1008CY; TO-92
R11, R12, R13, R14, R15, R16: 1K; RES_H

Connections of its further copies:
/IrController/OUT6: R11.2; also elsewhere on the board
/IrController/OUT7: R13.2; also elsewhere on the board
/IrController/OUT8: R15.2; also elsewhere on the board
/PowerSupply/L1: K6.3, K7.3, K8.3; also elsewhere on the board
/PowerSupply/L2: J8.1, J9.1, J10.1; also elsewhere on the board
/PowerSupply/N: J8.3, J9.3, J10.3; also elsewhere on the board
GND: Q6.1 (E), Q7.1 (E), Q8.1 (E); also elsewhere on the board
unnamed: D11.2 (A), D12.1 (K), K6.5, Q6.2 (C)
unnamed: D12.2 (A), R12.1
unnamed: D13.2 (A), D14.1 (K), K7.5, Q7.2 (C)
unnamed: D14.2 (A), R14.1
unnamed: D15.2 (A), D16.1 (K), K8.5, Q8.2 (C)
unnamed: D16.2 (A), R16.1
unnamed: J8.2, K6.2
unnamed: J9.2, K7.2
unnamed: J10.2, K8.2
unnamed: Q6.3 (B), R11.1
unnamed: Q7.3 (B), R13.1
unnamed: Q8.3 (B), R15.1
VCC: D11.1 (K), D13.1 (K), D15.1 (K), K6.1, K7.1, K8.1, R12.2, R14.2, R16.2; also elsewhere on the board

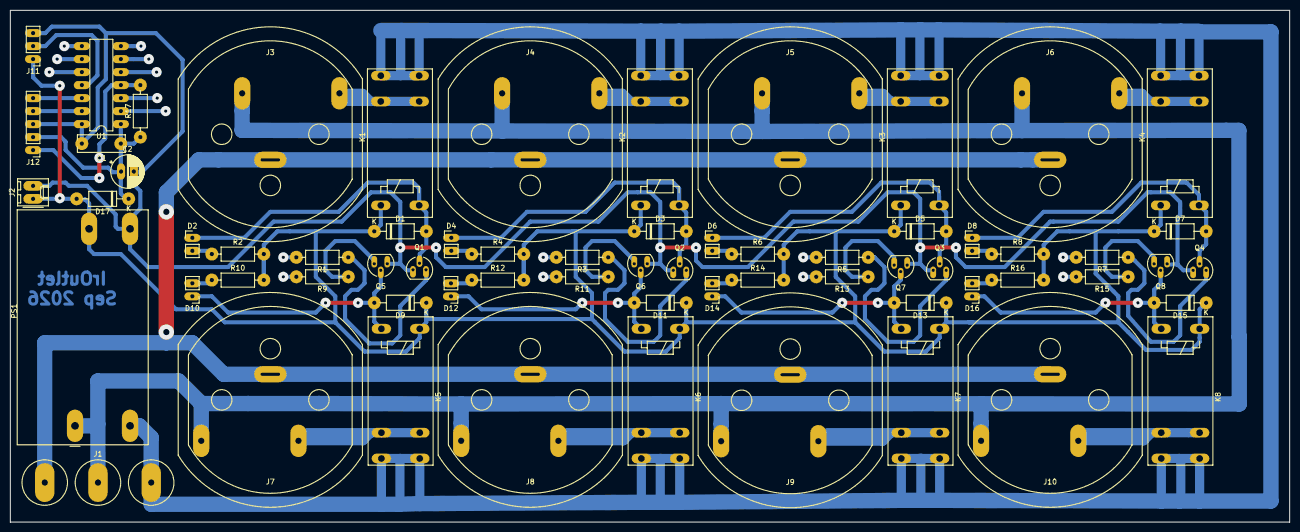
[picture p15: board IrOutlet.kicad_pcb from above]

Board: 2 copper layers, 250.0 x 100.0 mm, 66 parts (0 on the bottom side), 50 nets.

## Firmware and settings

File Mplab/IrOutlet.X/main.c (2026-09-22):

/**
 *
 *  @file   main.c
 *  @date   21-09-2026
 *  @author Bart Gysens
 *
 *  @brief  Main entry point.
 *
 */

/* --------------------------- *
 * Project and system includes *
 * --------------------------- */
#include <xc.h>
#include <stdbool.h>
#include "rc5.h"

/* ------------------------------ *
 * PIC16F15325 Configuration bits *
 * ------------------------------ */

/*-- CONFIG1 --*/
#pragma config FEXTOSC = OFF        // External Oscillator mode selection bits (Oscillator not enabled)
#pragma config RSTOSC = HFINT32     // Power-up default value for COSC bits (HFINTOSC with OSCFRQ= 32 MHz and CDIV = 1:1)
#pragma config CLKOUTEN = OFF       // Clock Out Enable bit (CLKOUT function is disabled; i/o or oscillator function on OSC2)
#pragma config CSWEN = OFF          // Clock Switch Enable bit (The NOSC and NDIV bits cannot be changed by user software)
#pragma config FCMEN = OFF          // Fail-Safe Clock Monitor Enable bit (FSCM timer disabled)

/*-- CONFIG2 --*/
#pragma config MCLRE = ON           // Master Clear Enable bit (MCLR pin is Master Clear function)
#pragma config PWRTE = OFF          // Power-up Timer Enable bit (PWRT disabled)
#pragma config LPBOREN = OFF        // Low-Power BOR enable bit (ULPBOR disabled)
#pragma config BOREN = OFF          // Brown-out reset enable bits (Brown-out reset disabled)
#pragma config BORV = LO            // Brown-out Reset Voltage Selection (Brown-out Reset Voltage (VBOR) set to 1.9V on LF, and 2.45V on F Devices)
#pragma config ZCD = OFF            // Zero-cross detect disable (Zero-cross detect circuit is disabled at POR.)
#pragma config PPS1WAY = OFF        // Peripheral Pin Select one-way control (The PPSLOCK bit can be set and cleared repeatedly by software)
#pragma config STVREN = ON          // Stack Overflow/Underflow Reset Enable bit (Stack Overflow or Underflow will cause a reset)

/*-- CONFIG3 --*/
#pragma config WDTCPS = WDTCPS_31   // WDT Period Select bits (Divider ratio 1:65536; software control of WDTPS)
#pragma config WDTE = OFF           // WDT operating mode (WDT Disabled, SWDTEN is ignored)
#pragma config WDTCWS = WDTCWS_7    // WDT Window Select bits (window always open (100%); software control; keyed access not required)
#pragma config WDTCCS = SC          // WDT input clock selector (Software Control)

/*-- CONFIG4 --*/
#pragma config BBSIZE = BB512       // Boot Block Size Selection bits (512 words boot block size)
#pragma config BBEN = OFF           // Boot Block Enable bit (Boot Block disabled)
#pragma config SAFEN = OFF          // SAF Enable bit (SAF disabled)
#pragma config WRTAPP = OFF         // Application Block Write Protection bit (Application Block not write protected)
#pragma config WRTB = OFF           // Boot Block Write Protection bit (Boot Block not write protected)
#pragma config WRTC = OFF           // Configuration Register Write Protection bit (Configuration Register not write protected)
#pragma config WRTSAF = OFF         // Storage Area Flash Write Protection bit (SAF not write protected)
#pragma config LVP = OFF            // Low Voltage Programming Enable bit (High Voltage on MCLR/Vpp must be used for programming)

/*-- CONFIG5 --*/
#pragma config CP = OFF             // UserNVM Program memory code protection bit (UserNVM code protection disabled)


/* -------------------- *
 * Forward declarations *
 * -------------------- */
void _initialize(void);
void _execute(void);



/**
 *
 *  Main entry point.
 *
 */
void main(void)
{
    /*-- initialize i/o and peripherals --*/
    _initialize();

    /*-- execute application --*/
    _execute();
}



/**
 *
 *  Initialize ports, peripherals & interrupts.
 *
 */
void _initialize(void)
{
    di();
    
    /*-- disable conflicting peripherals --*/
    PMD4bits.UART1MD = 1;   /* EUSART1 disabled */
    PMD4bits.UART2MD = 1;   /* EUSART2 disabled */
    PMD4bits.MSSP1MD = 1;   /* MSSP1 disabled */    
    
    /*-- initialize IO pins --*/
    PORTA &= 0b11001111;     /* reset pin value */
    LATA &= 0b11001111;      /* reset pin latch */
    ANSELA &= 0b11001111;    /* set as digital io */    
    ODCONA &= 0b11001111;    /* enable push-pull */
    SLRCONA &= 0b11001111;   /* disable rate limit */
    TRISA &= 0b11001111;     /* set as digital output pin */  
    
    PORTC &= 0b11000000;     /* reset pin value */
    LATC &= 0b11000000;      /* reset pin latch */
    ANSELC &= 0b11000000;    /* set as digital io */
    ODCONC &= 0b11000000;    /* enable push-pull */
    SLRCONC &= 0b11000000;   /* disable rate limit */
    TRISC &= 0b11000000;     /* set as digital output pin */
    
    rc5Setup();
    
    ei();
}



/**
 *
 *  Execute application.
 *
 */
void _execute(void)
{
    RC5_COMMAND rc5Command;    

    /*-- enter forever loop --*/
    for(;; NOP())
    {        
        if ( rc5Ready() == true )
        {
            /*-- cache data --*/
            di();                   /* disable interrupts */
            rc5Command = rc5Get();  /* store local copy of data */
            rc5Clear();             /* clear ready flag */            
            ei();                   /* enable interrupts */

            /*-- check if address is VCR1 (0b00101) (Medion MD83709: device VCR, brand marantz [code 0257]) --*/
            if (rc5Command.address == 0b00101 )
            {
                switch ( rc5Command.command )
                {
                    case 0b0000000: /* '0 */
                    {
                        /*-- switch all outlets on --*/
                        PORTC |= 0b00111111;
                        PORTA |= 0b00110000;                        
                        break;
                    }

                    case 0b0000001: /* '1' */
                    {
                        /*-- switch outlet 1 on --*/
                        PORTCbits.RC0 = 1;                        
                        break;
                    }

                    case 0b0000010: /* '2' */
                    {
                        /*-- swith outlet 2 on --*/
                        PORTCbits.RC1 = 1;
                        break;
                    }

                    case 0b0000011: /* '3' */
                    {
                        /*-- switch outlet 3 on --*/
                        PORTCbits.RC2 = 1;
                        break;
                    }

                    case 0b0000100: /* '4' */
                    {
                        /*-- switch outlet 4 on --*/
                        PORTCbits.RC3 = 1;
                        break;
                    }

                    case 0b0000101: /* '5' */
                    {
                        /*-- switch outlet 5 on --*/
                        PORTCbits.RC4 = 1;
                        break;
                    }
                    
                    case 0b0000110: /* '6' */
                    {
                        /*-- switch outlet 6 on --*/
                        PORTCbits.RC5 = 1;
                        break;
                    }

                    case 0b0000111: /* '7' */
                    {
                        /*-- switch outlet 7 on --*/
                        PORTAbits.RA4 = 1;
                        break;
                    }

                    case 0b0001000: /* '8' */
                    {
                        /*-- switch outlet 8 on --*/
                        PORTAbits.RA5 = 1;
                        break;
                    }

                    case 0b0001001: /* '9' */
                    {
                        /*-- switch all outlets off --*/
                        PORTC &= 0b11000000;
                        PORTA &= 0b11001111;
                        break;
                    }
                    
                    case 0b00100000: /* 'PGM+' */
                    {
                        /*-- switch outlet 1 off --*/
                        PORTCbits.RC0 = 0;
                        break;
                    }

                    case 0b00100001: /* 'PGM-' */
                    {
                        /*-- switch outlet 2 off --*/
                        PORTCbits.RC1 = 0;
                        break;
                    }
                    
                    case 0b00110010: /* '<<' */
                    {
                        /*-- switch outlet 3 off --*/
                        PORTCbits.RC2 = 0;
                        break;
                    }

                    case 0b00110101: /* '>' */
                    {
                        /*-- switch outlet 4 off --*/
                        PORTCbits.RC3 = 0;
                        break;
                    }

                    case 0b00110100: /* '>>' */
                    {
                        /*-- switch outlet 5 off --*/
                        PORTCbits.RC4 = 0;
                        break;
                    }

                    case 0b00110110: /* '[]' */
                    {
                        /*-- switch outlet 6 off --*/
                        PORTCbits.RC5 = 0;
                        break;
                    }

                    case 0b00101001: /* '||' */
                    {
                        /*-- switch outlet 7 off --*/
                        PORTAbits.RA4 = 0;
                        break;
                    }

                    case 0b00111110: /* 'AV' */
                    {
                        /*-- switch outlet 8 off --*/
                        PORTAbits.RA5 = 0;
                        break;
                    }

                    default:
                    {
                        /*-- do nothing --*/
                        break;
                    }
                }                                
            }                        
        }
    }
}
